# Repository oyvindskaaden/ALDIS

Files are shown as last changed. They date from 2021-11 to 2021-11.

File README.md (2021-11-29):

# ALDIS
ALDIS is a system to communicate between a theater stage and FOH

## System

The system consists of two equal endpoints.
They communicate with a simple protocol, syncing with eachother.
The protocol does contain a simple CRC8 checksum, to compensate for large distances between stage and FOH.

## Connections 

The simplest way to connect the two endpoints together is via a ethernet cable. 

There are four wires that need to be connected. 
Use the four pairs of the ethernet.
Almost all stages have some spare ethernet between FOH and stage.

### Interconnect

The device uses ehtercon as the physical layer.

The RX and TX OUT are RX and TX on the device in the box.

| Pair | What |
| :----- | :----- |
| Orange | +5V |
| Blue | Ground |
| Green  | RX OUT |
| Brown  | TX OUT |

These should be connected to the remote as follows.

* RX OUT -> TX on remote
* TX OUT -> RX on remote

### Local led connect (XLR 5-pin)

| XLR Pin | LED Pin |
| :-----: | :--- |
| 1 | Red |
| 2 | NC |
| 3 | Ground  |
| 4 | Blue |
| 5 | Green |

## Schematics

The schematics are included in [`schematics/`](schematics/) as a [PDF](schematics/aldis_main.pdf) and a [KiKad project](schematics/ALDIS/ALDIS.pro).

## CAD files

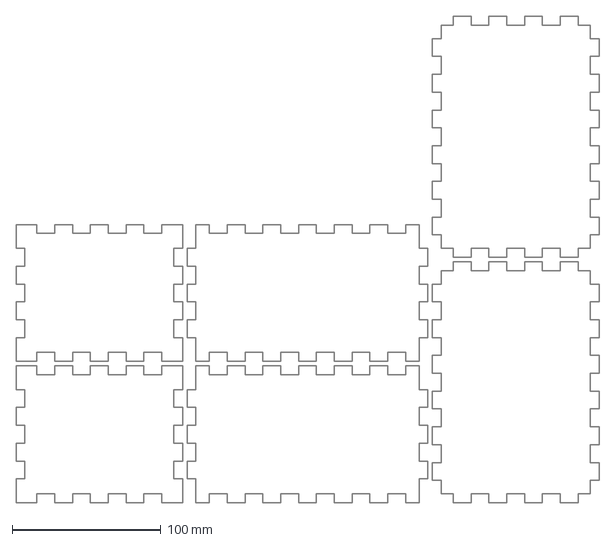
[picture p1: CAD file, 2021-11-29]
enclosure/6mmKryss.dxf
392.0 x 327.0 mm

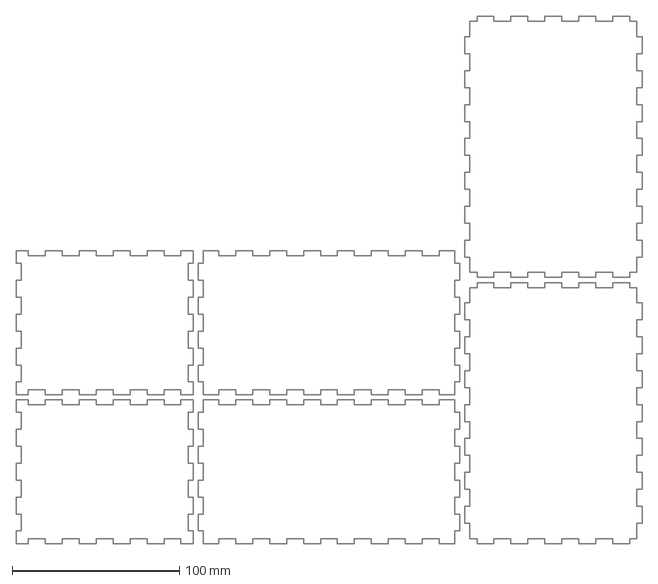
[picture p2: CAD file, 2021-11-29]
enclosure/3mmKryss.dxf
374.0 x 315.0 mm

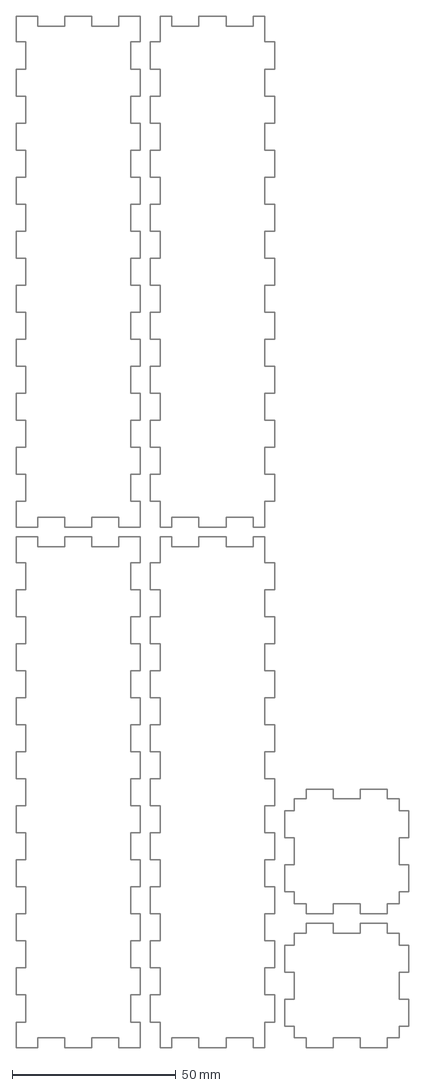
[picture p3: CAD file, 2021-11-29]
enclosure/knappeboksScene.dxf
120.0 x 315.0 mm

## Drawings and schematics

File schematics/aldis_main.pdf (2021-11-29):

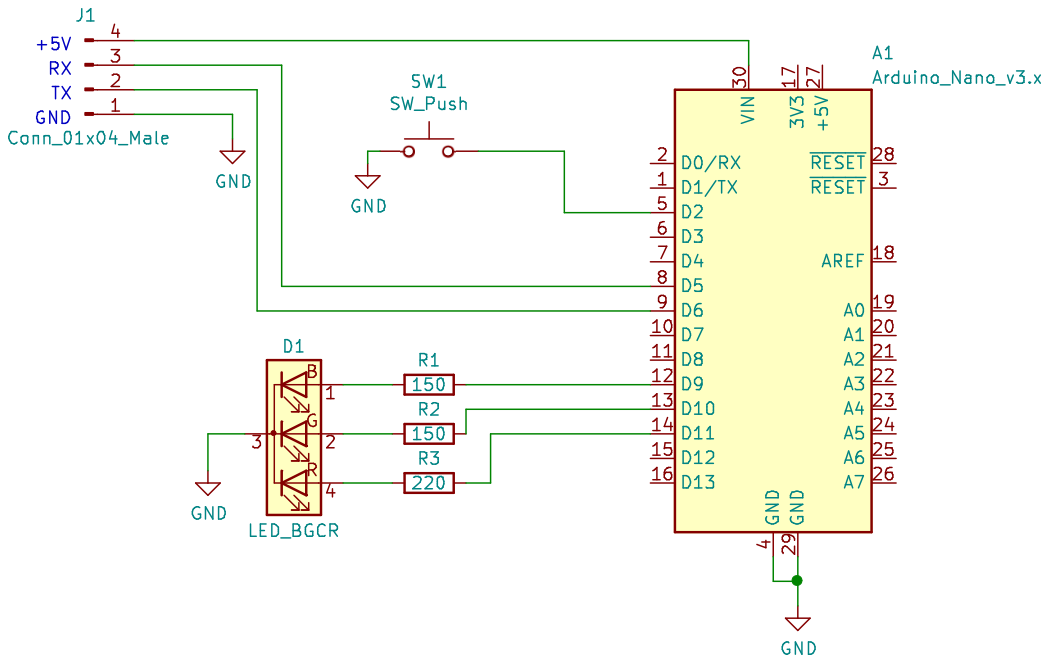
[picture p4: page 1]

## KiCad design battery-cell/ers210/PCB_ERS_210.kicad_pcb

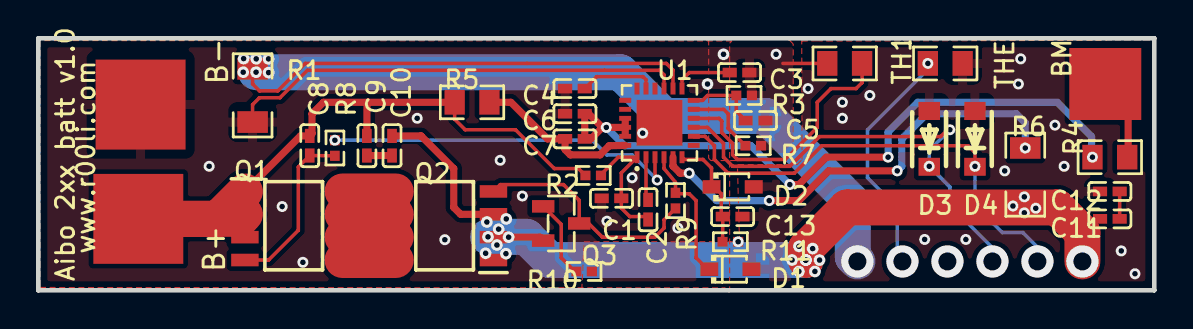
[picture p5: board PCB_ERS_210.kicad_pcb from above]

Board: 2 copper layers, 62.0 x 14.0 mm, 37 parts (0 on the bottom side), 26 nets.

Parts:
B+: BATT+; PAD-1X-5X5MM
B-: BATT-; PAD-1X-5X5MM
BM: BATTM; PAD-1X-5X5MM
C1, C8, C9, C10, C11, C12: 0.1uF; C0402
C2, C3, C4, C5: 0.47uF; C0402
C6, C7, C13: 0.01uF; C0402
D1: SD101BW-7-F; SOD-323_L1.8-W1.3-LS2.5-RD
D2: SD103AWS-E3-08; SOD-323_L1.8-W1.3-LS2.5-RD
D3, D4: BZT52H-B5V6,115; SOD-123F_L2.8-W1.8-LS3.7-RD
Q1, Q2: IRF8714TRPBF; SOIC127P600X175-8N
Q3: 2N7002; SOT-23-3_L2.9-W1.3-P1.90-LS2.4-BR
R1: 0.005; R1206
R2: 10; R0402
R3, R10: 10k; R0402
R4, R5: 49.9; R0805
R6: 2k; R1206
R7, R11: 1k; R0402
R8, R9: 100; R0402
TH1: NTC 100k; R0805
THE: NTC 100k; R0805
U1: MAX17320G22+; QFN-24_L4.0-W4.0-P0.50-BL-EP2.6

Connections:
BATTM: BM.1, R4.2
BATTN: B-.1, C1.2, C3.1, C4.1, C5.2, C6.1, R1.2, R3.1, R7.1, TH1.1, U1.20, U1.25
BATTP: B+.1, C8.2, C9.2, Q1.1, Q1.2, Q1.3, R2.1, R5.2
C9_1: C9.1, C10.2
C11_2: C11.2, C12.1
CHG: R8.1, U1.3
DIS: D1.1, R9.1, U1.4
OUT_BATTN: C12.2, C13.2, D1.2, D2.2, D3.2, D4.2, R1.1, R10.1, THE.1
OUT_BATTP: C10.1, C11.1, Q2.1, Q2.2, Q2.3, Q3.2, R6.1, R11.2
PCKP: C13.1, D2.1, R11.1, U1.6
PFAIL: R7.2, U1.11
Q1_4: C8.1, Q1.4, R8.2
Q1_8: Q1.5, Q1.6, Q1.7, Q1.8, Q2.5, Q2.6, Q2.7, Q2.8
Q2_4: Q2.4, Q3.3, R9.2
Q3_1: Q3.1, R10.2
SCL: D4.1, U1.8
SDA: D3.1, U1.9
TH1: TH1.2, U1.10
U1_1: C1.1, C2.2, R2.2, U1.1
U1_2: C2.1, U1.2
U1_5: R6.2, U1.5
U1_12: C5.1, R3.2, U1.12
U1_13: C3.2, U1.13
U1_17: C4.2, U1.17
U1_21: C6.2, C7.2, R4.1, U1.21, U1.22, U1.23
U1_24: C7.1, R5.1, U1.24

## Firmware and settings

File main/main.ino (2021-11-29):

#include <SoftwareSerial.h>

#define   BUSY_BLINK_PERIOD_MS    250
#define   TIMEOUT_BLINK_PERIOD_MS 500
#define   RDY_BLINK_PERIOD_MS     250
#define   IDLE_PULSE_PERIOD_MS    8
#define   TIMEOUT_PULSE_PERIOD_MS 1
#define   TIMEOUT_DELAY_MS        30000
#define   TIME_TO_IDLE_MS         3000   

#define   SERIAL_SOF              0x88
#define   SERIAL_MAX_LEN          5
#define   SERIAL_DATA_LEN         3

#define   BUTTON_DEBOUNCE_DLY_MS  500
#define   START_UP_DLY_MS         500

enum class SerialCMD : uint8_t {
  STATE       = 0x10,
  BUTTON      = 0x20
};

enum class BaudRate : uint32_t {
  BAUD_9600   = 9600,
  BAUD_14400  = 14400,
  BAUD_19200  = 19200, 
  BAUD_38400  = 38400, 
  BAUD_57600  = 57600, 
  BAUD_115200 = 115200
};

enum class State : uint8_t{
  IDLE,
  STAGE_BUSY,
  TIMEOUT,
  STAGE_RDY
};

struct RGB {
  bool red;
  bool green;
  bool blue;
};


enum class PacketState {
  GET_SOF,
  GET_DATA
};

struct PacketInfo {
  PacketState state;
  uint8_t     len;
  uint8_t     data[3];
};

PacketInfo packet {
  .state  = PacketState::GET_SOF,
  .len    = 0
};



State state = State::IDLE;
State nextState = State::STAGE_BUSY;
uint32_t lastChange = 0;
uint32_t stateNow = 0;


uint8_t nextIntensity  = 255;
bool isReducingIntensity  = true;
uint32_t now = 0;
uint32_t then = 0;
bool isLedOn = false;

SoftwareSerial uart(5, 6); // RX -> Pin 5, TX -> Pin 6

// Red: Pin 11, Green: Pin 10, Blue: Pin 9
uint8_t rgbPins[3] = {11, 10, 9};
uint8_t button = 2;


RGB stateColors[4] {
  {0, 0, 1},  //! IDLE        -> Blue
  {1, 0, 0},  //! STAGE_BUSY  -> Red
  {1, 1, 0},  //! TIMEOUT     -> Yellow
  {0, 1, 0}   //! STAGE_RDY   -> Green
};


uint32_t lastPress = millis();
// Global ISR
void ChangeStateISR() {
  // Software debouncer
  if (millis() - lastPress > BUTTON_DEBOUNCE_DLY_MS){
    lastPress = millis();

    // Actual ISR
    lastChange = millis();
    state = nextState;
  }
}


// Table used for CRC calculation
uint8_t crcLookup[256] = {
  0x00, 0x91, 0xE3, 0x72, 0x07, 0x96, 0xE4, 0x75, 0x0E, 0x9F, 0xED, 0x7C, 0x09, 0x98, 0xEA, 0x7B, 
  0x1C, 0x8D, 0xFF, 0x6E, 0x1B, 0x8A, 0xF8, 0x69, 0x12, 0x83, 0xF1, 0x60, 0x15, 0x84, 0xF6, 0x67, 
  0x38, 0xA9, 0xDB, 0x4A, 0x3F, 0xAE, 0xDC, 0x4D, 0x36, 0xA7, 0xD5, 0x44, 0x31, 0xA0, 0xD2, 0x43, 
  0x24, 0xB5, 0xC7, 0x56, 0x23, 0xB2, 0xC0, 0x51, 0x2A, 0xBB, 0xC9, 0x58, 0x2D, 0xBC, 0xCE, 0x5F, 
  0x70, 0xE1, 0x93, 0x02, 0x77, 0xE6, 0x94, 0x05, 0x7E, 0xEF, 0x9D, 0x0C, 0x79, 0xE8, 0x9A, 0x0B, 
  0x6C, 0xFD, 0x8F, 0x1E, 0x6B, 0xFA, 0x88, 0x19, 0x62, 0xF3, 0x81, 0x10, 0x65, 0xF4, 0x86, 0x17, 
  0x48, 0xD9, 0xAB, 0x3A, 0x4F, 0xDE, 0xAC, 0x3D, 0x46, 0xD7, 0xA5, 0x34, 0x41, 0xD0, 0xA2, 0x33, 
  0x54, 0xC5, 0xB7, 0x26, 0x53, 0xC2, 0xB0, 0x21, 0x5A, 0xCB, 0xB9, 0x28, 0x5D, 0xCC, 0xBE, 0x2F, 
  0xE0, 0x71, 0x03, 0x92, 0xE7, 0x76, 0x04, 0x95, 0xEE, 0x7F, 0x0D, 0x9C, 0xE9, 0x78, 0x0A, 0x9B, 
  0xFC, 0x6D, 0x1F, 0x8E, 0xFB, 0x6A, 0x18, 0x89, 0xF2, 0x63, 0x11, 0x80, 0xF5, 0x64, 0x16, 0x87, 
  0xD8, 0x49, 0x3B, 0xAA, 0xDF, 0x4E, 0x3C, 0xAD, 0xD6, 0x47, 0x35, 0xA4, 0xD1, 0x40, 0x32, 0xA3, 
  0xC4, 0x55, 0x27, 0xB6, 0xC3, 0x52, 0x20, 0xB1, 0xCA, 0x5B, 0x29, 0xB8, 0xCD, 0x5C, 0x2E, 0xBF, 
  0x90, 0x01, 0x73, 0xE2, 0x97, 0x06, 0x74, 0xE5, 0x9E, 0x0F, 0x7D, 0xEC, 0x99, 0x08, 0x7A, 0xEB, 
  0x8C, 0x1D, 0x6F, 0xFE, 0x8B, 0x1A, 0x68, 0xF9, 0x82, 0x13, 0x61, 0xF0, 0x85, 0x14, 0x66, 0xF7, 
  0xA8, 0x39, 0x4B, 0xDA, 0xAF, 0x3E, 0x4C, 0xDD, 0xA6, 0x37, 0x45, 0xD4, 0xA1, 0x30, 0x42, 0xD3, 
  0xB4, 0x25, 0x57, 0xC6, 0xB3, 0x22, 0x50, 0xC1, 0xBA, 0x2B, 0x59, 0xC8, 0xBD, 0x2C, 0x5E, 0xCF
};


uint8_t CRC8(uint8_t *pData, uint8_t len) {
  uint8_t crc = 0;
  while (len--) {
    uint8_t data = crc ^ *pData++;
    crc = crcLookup[data];
  }
  return crc;
}

void DecodePacket(uint8_t data[3]) {
  switch ((SerialCMD)data[0])
  {
  case SerialCMD::STATE:
    if (data[1] <= (uint8_t)State::STAGE_RDY) {
      lastChange = millis();
      state = (State)data[1];
    }
    break;
  case SerialCMD::BUTTON:
    ChangeStateISR();
    break;
  
  default:
    break;
  }
}


void SendState() {
  uint8_t data[5] = {SERIAL_SOF, SERIAL_SOF, (uint8_t)SerialCMD::STATE, (uint8_t)state, 0x00};

  data[4] = CRC8(&data[2], 2);

  //Serial.write(data, sizeof(data));
  uart.write(data, sizeof(data));
}

void ReceiveData() {
  
  //if (Serial.available() > 0) {
    //uint8_t read = Serial.read();
  if (uart.available() > 0) {
    uint8_t read = uart.read();

    switch (packet.state)
    {
    case PacketState::GET_SOF:
      if (read == SERIAL_SOF)
        packet.len++;
      if (packet.len == 2) {
        packet.len = 0;
        packet.state = PacketState::GET_DATA;
      }

      break;
    case PacketState::GET_DATA:
      if (read == SERIAL_SOF)
        break;
      packet.data[packet.len++] = read;

      if (packet.len == SERIAL_DATA_LEN) {
        if (!CRC8(packet.data, SERIAL_DATA_LEN))
          DecodePacket(packet.data);
        packet.len = 0;
        packet.state = PacketState::GET_SOF;
      }
      break;
    }

  }

}


void WriteRGB (uint8_t rgb_pins[3], RGB rgb, uint8_t intensity) {
  analogWrite(rgb_pins[0], rgb.red * intensity);
  analogWrite(rgb_pins[1], rgb.green * intensity);
  analogWrite(rgb_pins[2], rgb.blue * intensity);
}


void WriteRGB (uint8_t rgb_pins[3], RGB rgb) {
  WriteRGB(rgb_pins, rgb, 255);
}


void PulseLeds(State state, uint8_t delay) {
  if ((now = millis()) - then > delay) {
    then = now;

    WriteRGB(rgbPins, stateColors[(uint8_t)state], nextIntensity);

    if (isReducingIntensity) {
      if (nextIntensity > 0)
        nextIntensity--;
      else
        isReducingIntensity = false;
    }
    else {
      if (nextIntensity < 255)
        nextIntensity++;
      else
        isReducingIntensity = true;
    }
  }
}


void BlinkLeds(State state, uint16_t delay) {
  if ((now = millis()) - then > delay) {
    then = now;

    isLedOn = !isLedOn;
    nextIntensity = isLedOn * 255;

    WriteRGB(rgbPins, stateColors[(uint8_t)state], nextIntensity);
  }
}


void DoIdleState() {
  nextState = State::STAGE_BUSY;

  PulseLeds(State::IDLE, IDLE_PULSE_PERIOD_MS);
}


void DoStageBusyState(bool isPaused) {
  if (millis() - lastChange > TIMEOUT_DELAY_MS && !isPaused) {
    lastChange = millis();
    state = State::TIMEOUT;
  }

  nextState = State::STAGE_RDY;
  BlinkLeds(State::STAGE_BUSY, BUSY_BLINK_PERIOD_MS);
}


void DoTimeoutState() {
  nextState = State::STAGE_RDY;
  
  PulseLeds(State::TIMEOUT, TIMEOUT_PULSE_PERIOD_MS);
}


void DoStageReadyState() {

  if (millis() - lastChange > TIME_TO_IDLE_MS) {
    lastChange = millis();
    state = State::IDLE;
    nextState = State::STAGE_BUSY;
  }

  nextState = State::IDLE;
  BlinkLeds(State::STAGE_RDY, RDY_BLINK_PERIOD_MS);
}





void setup() {
  for (uint8_t p : rgbPins) {
    pinMode(p, OUTPUT);
  }
  pinMode(button, INPUT_PULLUP);

  attachInterrupt(digitalPinToInterrupt(button), ChangeStateISR, RISING);
  Serial.begin((long)BaudRate::BAUD_9600);

  
  uart.begin((long)BaudRate::BAUD_9600);

  delay(START_UP_DLY_MS);
}

State lastState = State::IDLE;
void loop() {

  if(lastState != state) {
    SendState();
    lastState = state;
  }
  switch (state) {
  case State::IDLE:
    DoIdleState();
    break;
  case State::STAGE_BUSY:
    DoStageBusyState(!digitalRead(button));
    break;
  case State::TIMEOUT:
    DoTimeoutState();
    break;
  case State::STAGE_RDY:
    DoStageReadyState();
    break;
  }

  ReceiveData();

}

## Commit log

2021-11-29 Added enclosure
    [3mmKryss.dxf, 6mmKryss.dxf, knappeboksScene.dxf]
2021-11-29 Added schematics
    [ALDIS.kicad_pcb, ALDIS.sch]
